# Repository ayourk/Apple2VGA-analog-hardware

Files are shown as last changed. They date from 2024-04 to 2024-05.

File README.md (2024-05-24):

V2Logo 

# Clone of ∀2 Retro Computing Analog VGA Card & PicoPal
PicoPal Logo

Design files for the ∀2 Analog series of VGA cards

## Description
Modified version of V2RetroComputing's Apple II Analog VGA Expansion Board using KiCAD 6.0.x. <br />
Changes from original:
* Moved solder jumpers to the back of the board for both the (lack of) PAL/GAL and non WiFi Pico.
* Reorganized Schematic to more easily generate a BOM with Part numbers from LSCS, DigiKey, and Mouser.
* Adopted Hans Hübner's VGA port connector break-away feature. Also reworked board to be 2 layers vs 4 layers but kept 4x bus transcievers vs Han's 2 since the chip in the 4x variant is easier to obtain.
* Added a PLCC socket for the PAL/GAL chip that is getting difficult to find.  Be sure to bridge the solder jumper on the back if you don't plan to populate this socket.
* Re-adjusted layout to provide more Analog VGA signal clarity by making the traces as short as possible between the VGA port connector and the PICO.
* Switched from IDC header style to a shielded FPC cable for less chance of signal interference when using the optional break-away feature.
* Rounded off PCB corners where it made sense.  I hate getting stabbed by PCBs (Grrrr)!

This board should still be binary compatible with the software this hardware was forked from.

### PCB Layout
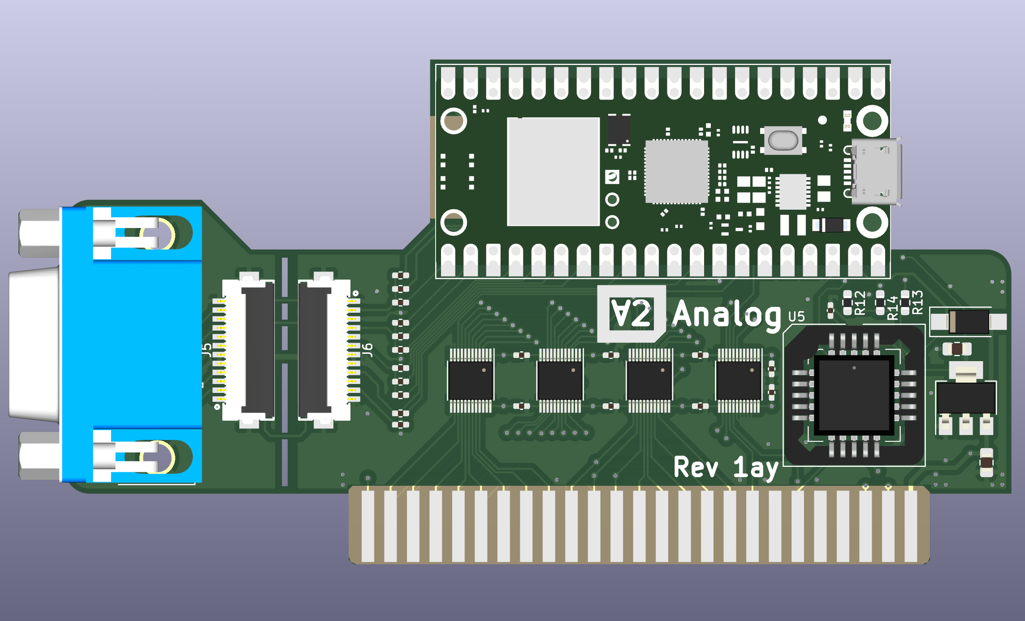
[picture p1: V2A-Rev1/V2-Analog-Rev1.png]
A2VGA Board Image V2RetroComputing's Apple II Analog VGA card


### See Also
https://github.com/V2RetroComputing/analog <br />
https://github.com/ayourk/Apple2Analog-VGA <br />
https://github.com/hanshuebner/AppleII-VGA <br />
https://github.com/markadev/AppleII-VGA <br />
[Apple II Expansion Card Size Specifications](V2A-Rev1/docs/Apple_II_ExpansionCard_Spec.txt) <br />
[Apple II Expansion Slot Pinout](V2A-Rev1/docs/Apple2SlotPinout.html) <br />
[Apple II Hardware Reference](V2A-Rev1/docs/Apple2HardwareReference.pdf) <br />
https://github.com/ayourk/Apple2Proto <br />

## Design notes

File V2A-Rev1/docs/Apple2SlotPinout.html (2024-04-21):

# Apple II Peripheral Card connector pinout

The arrow in the middle of the drawing points to the front of the Apple II | 1 | I/O SELECT | This line, normal high, will become low when the microprocessor references page $Cn, where n is the individual slot number. This signal becomes active during 00 and will drive 10 LSTTL loads*. This signal is not present on peripheral connector 0 (II+)
| 2-17 | A0-A15 | The buffered address bus. The address on these lines becomes valid during 01 and remains valid through 00. These lines will each drive 5 LSTTL loads.
| 18 | R/W | Buffered Read/Write signal. This becomes valid at the same time the address bus does, and goes high during a read cycle and low during a write. This line can drive up to 2 LSTTL loads *.
| 19 | SYNC | On peripheral connector 7 ONLY, this pin is connected to the video timing generator's SYNC signal.
| 20 | I/O STROBE | This line goes low during 00 when the address bus contains an address between $C800 and $CFFF. This line will drive 4 LSTTL loads*.
| 21 | READY | The 6502's RDY input. Pulling this line low during 01 will halt the microprocessor, with the address bus holding the address of the current location being fetched
| 22 | DMA | Pulling this line low disables the 6502's address bus and halts the microprocessor. This line is held high with a 3k resistor to +5v
| 23 | INT OUT | Daisy-chained interrupt output to lower priority devices. This pin is usually connected to pin 28 (INT IN)
| 24 | DMA OUT | Daisy-chained DMA output to lower priority devices. This pin is usually connected to pin 22 (DMA IN)
| 25 | +5V | +5 volt power supply. 500mA current is available for ALL peripheral cards.
| 26 | GND | System electrical ground
| 27 | DMA IN | Daisy-chained DMA input from higher priority devices. Usually connected to pin 24 (DMA OUT)
| 28 | INT IN | Daisy-chained interrupt input from higher priority devices. Usually connected to pin 23 (INT OUT)
| 29 | NMI | Non-Maskable Interrupt. When this line is pulled low the Apple II computer begins an interrupt cycle and jumps to the interrupt handling routine at location $3FB.
| 30 | IRQ | Interrupt ReQuest. When this line is pulled low the Apple II computer begins an interrupt cycle only if the 6502's I (Interrupt disable) flag is not set. If so, the 6502 will jump to the interrupt handling routine whose address is stored in locations $3FE and $3FF
| 31 | RESET | When this line is pulled low the microprocessor begins a RESET cycle (see page 36 of the Apple II Hardware Reference)
| 32 | INH | When this line is pulled low, all ROMs on the Apple board are disabled. This line is held high by a 2k resistor to +5v
| 33 | -12V | -12 volt power supply. Maximum current is 200mA for all peripheral boards.
| 34 | -5V | -5 volt power supply. Maximum current is 200mA for all peripheral boards
| 35 | COLOR REF | On peripheral connector 7 ONLY, this pin is connected to the 3.5Mhz COLOR REFerence signal of the video generator
| 36 | 7M | 7Mhz clock. This line will drive 2 LSTTL loads*.
| 37 | Q3 | 2Mhz asymmetrical clock. This line will drive 2 LSTTL loads*.
| 38 | Phi 01 | Microprocessor's phase one clock. This line will drive 2 LSTTL loads *.
| 39 | USER 1 | This line, when pulled low, disables ALL internal I/O address decoding**.
| 40 | Phi 00 | Microprocessors phase zero clock. This line will drive 2 LSTTL loads*.
| 41 | DEVICE SELECT | This line becomes active (low) on each peripheral connector when the address bus is holding an address between $con) and $C0nF, where n is the slot number plus $8. This line will drive 10 LSTTL loads*.
| 42-49 | D0-D7 | Buffered bi-directional data bus. The data on this line becomes valid 300nS into 00 on a write cycle, and should be stable no less than 100nS before the end of 00 on a read cycle. Each data line can drive one LSTTL load.
| 50 | +12V | +12 volt power supply. This can supply up to 250mA total for all peripheral cards.

Original information available from here (https://osites.tripod.com/peripheral.html).

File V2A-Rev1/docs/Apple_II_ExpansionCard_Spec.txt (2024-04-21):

From https://web.pdx.edu/~heiss/technotes/iigs/tn.iigs.028.html
via Archive.org: https://web.archive.org/web/20070624190021/https://web.pdx.edu/~heiss/technotes/iigs/tn.iigs.028.html

Apple IIgs #28
Interface Card Design Guidelines
Revised by Matt Deatherage (November 1988)
Written by Cameron Birse (October 1987)
This Technical Note describes suggested dimensions for interface cards for the Apple IIGS and Apple IIe upgraded sytems.

|----------------------7.00"----------------------|
__________________________________________________ __  __
|                                                 | |   |
|    The 7" dimension is specified for slots      | |   |
|    1-3 because of the optional fan which        | |   |
|    mounts on the power supply.                  | |   |
|                                                 |2.75"|
|                                                 | |   |
|                                                 | |  3.05"
|                  SLOTS 1 - 3                    | |   |
|                                                 | |   |
|_____________________________                  __|__   |
                             |__________________|_|______
                             |-------2.950"-----|-|-.375"

     |-------------------------10.00"-----------------------------------|
     |-----2.25"----|-----------------------7.75"-----------------------|
     |              ____________________________________________________ __  __
     |          _ ~                                                     | |   |
     |     _ ~                                                          | |   |
 ____ _ ~                                                               | |   |
 |   |                                                                  | |   |
 |   |                                                                  |2.75"|
 |   |                                                                  | |   |
2.20"|                                                                  | 3.05"
 |   |                       SLOTS 4 - 7                                | |   |
 |   |                                                                  | |   |
 __  |______________________________________________                  __|__   |
                                                   |__________________|_|______
                                                   |-------2.950"-----|-|-.375"

     |-------------------------10.00"-----------------------------------|
     |-----2.25"----|-----------------------7.75"-----------------------|
     |              ____________________________________________________ __
     |          _ ~                                                     | |
     |     _ ~                                                          | |
 ____ _ ~                                                               | |
 |   |                                                                  | |
 |   |                                                                  |2.75"
 |   |                                                                  | |
2.20"|                                                                  | |
 |   |                       SLOTS 4 - 7                                | |
 |   |                                                                  | |
 ____|_______                _________________   _______________________|_____
.35" |-.750-|                |                |  |                  .630" -|
 ____|______|________________|                |__|_________________________|__
     |--------3.02"----------|                |  |                         |
     |---------------------6.385"-------------|--|----------3.215"---------|
                                              .40"

Technical Notes
This and all of the other Apple II Technical Notes have been converted to HTML by Aaron Heiss as a public service to the Apple II community, with permission by Apple Computer, Inc. Any and all trademarks, registered and otherwise, are properties of their owners.

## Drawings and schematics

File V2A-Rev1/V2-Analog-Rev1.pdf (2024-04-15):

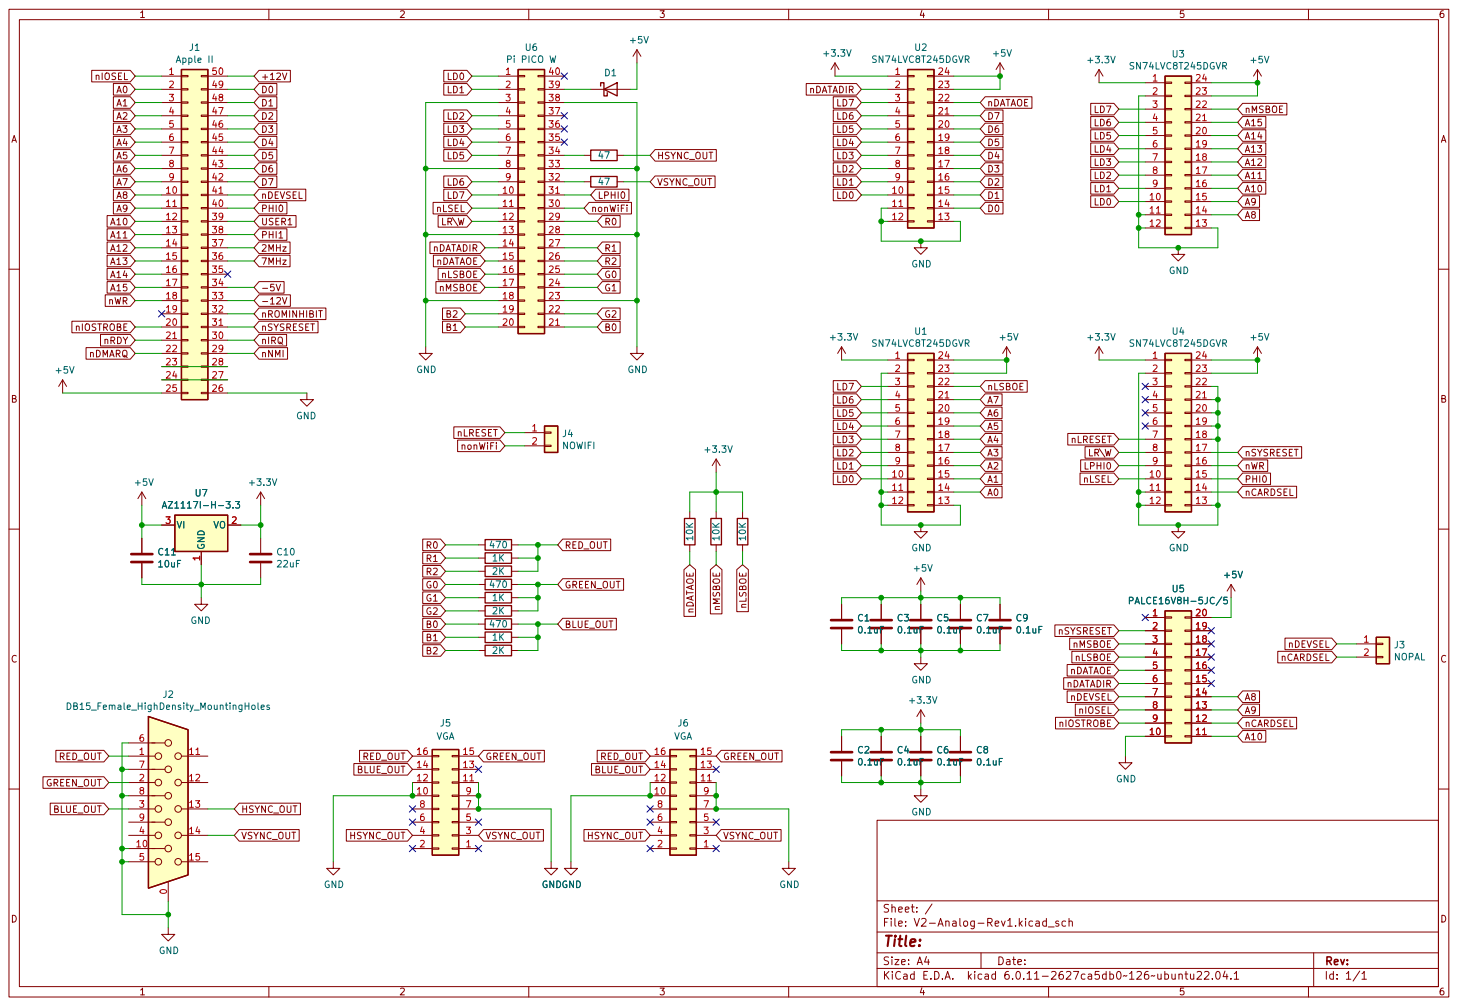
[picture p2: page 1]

Id: 1/1 Title: File: V2-Analog-Rev1.kicad_sch Sheet: / C10

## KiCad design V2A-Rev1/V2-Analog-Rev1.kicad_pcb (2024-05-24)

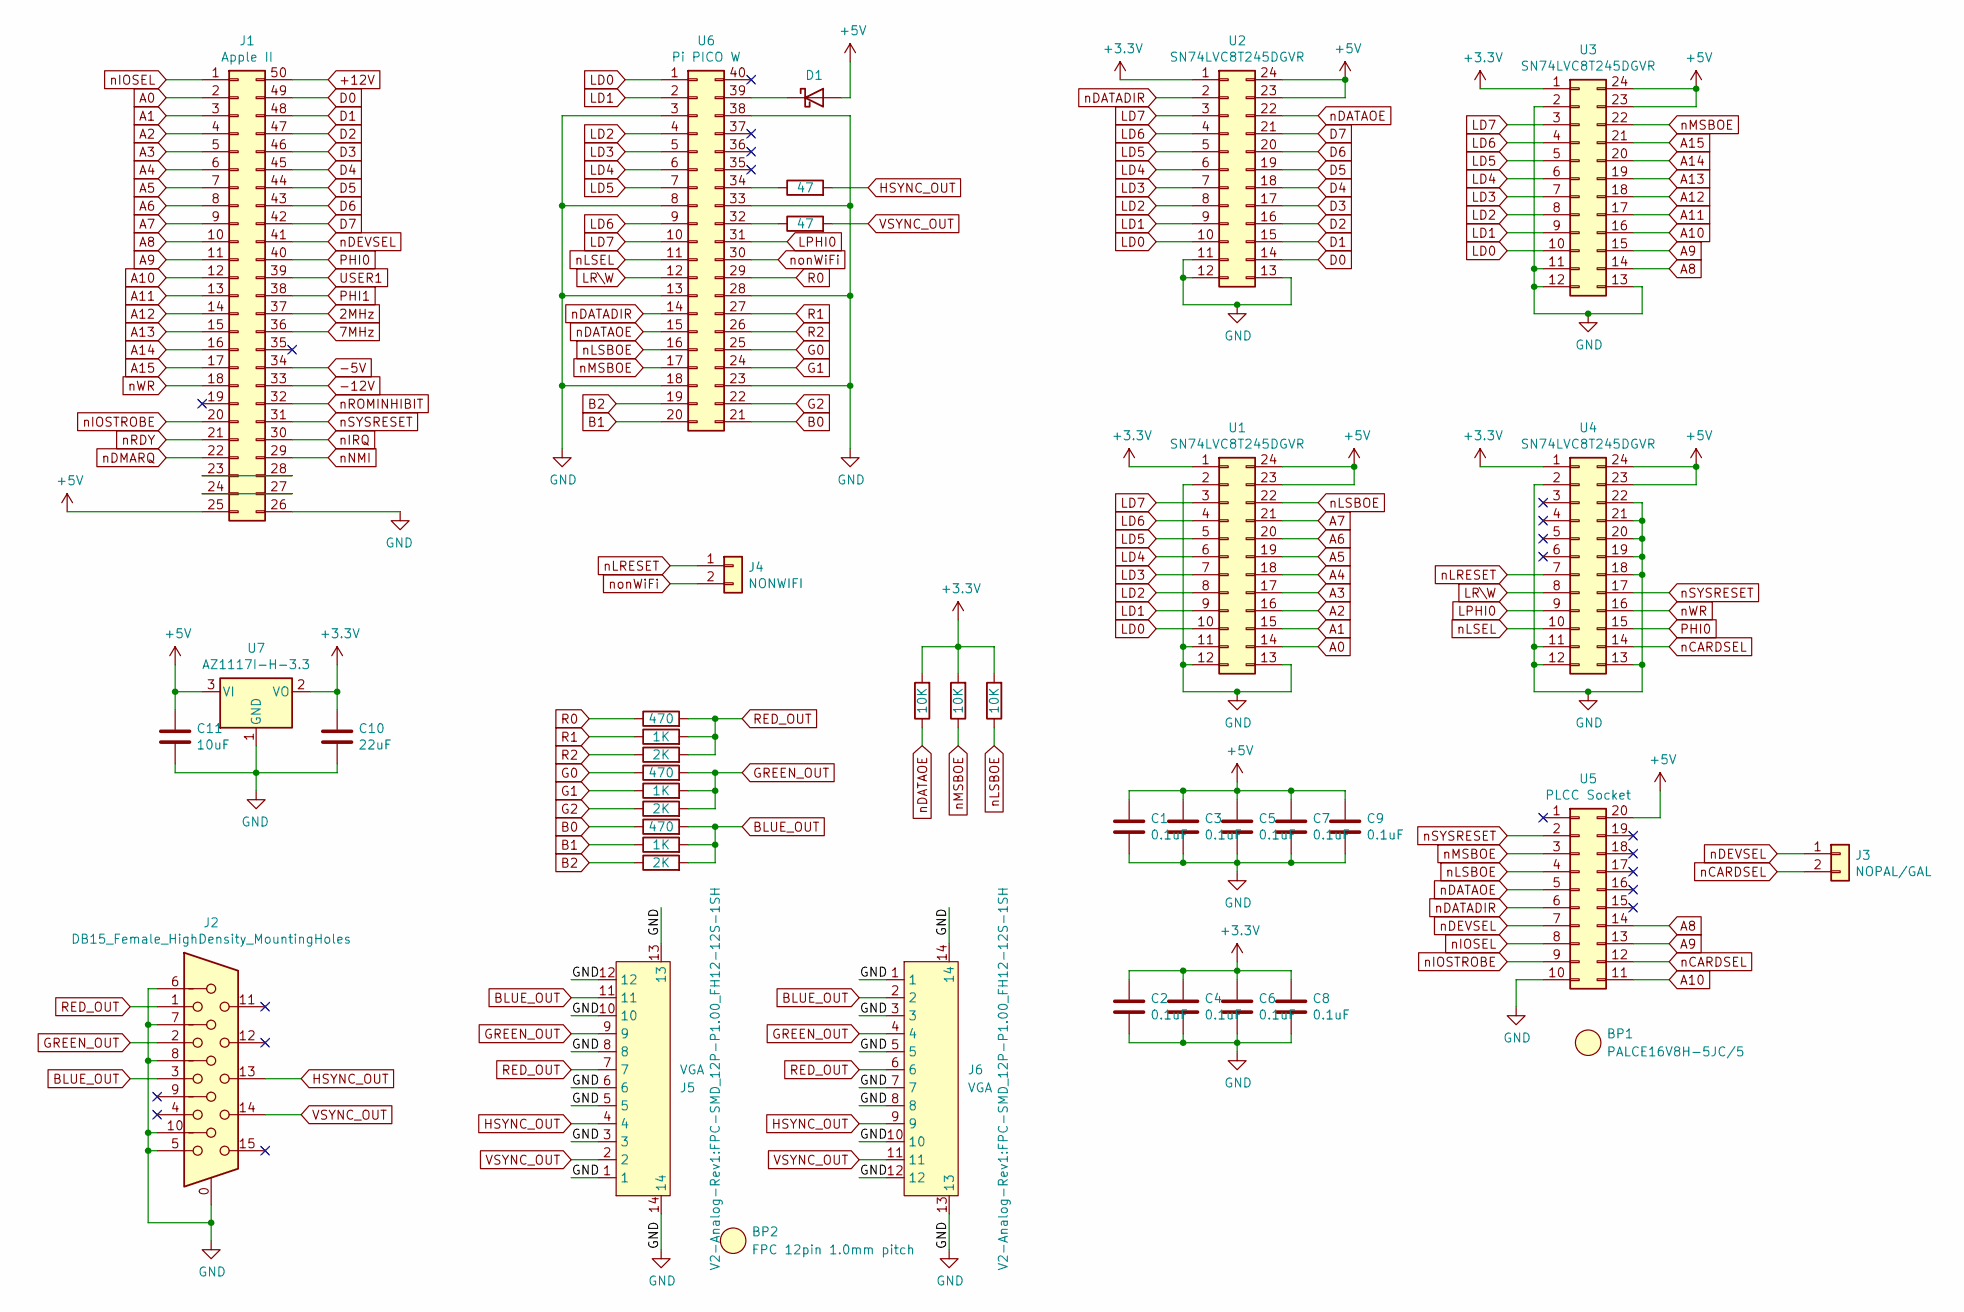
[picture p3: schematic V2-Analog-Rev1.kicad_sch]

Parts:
BP1: PALCE16V8H-5JC/5; BOM_Placeholder; MPN PALCE16V8H-5JC/5; LCSC C3292615
BP2: FPC 12pin 1.0mm pitch; BOM_Placeholder; MPN 0152670279; LCSC C18108667
C1, C2, C3, C4, C5, C6, C7, C8, C9: 0.1uF; C_0402_1005Metric_Pad0.74x0.62mm_HandSolder; MPN CL05B104KA5NNNC; LCSC C155422
C10: 22uF; C_0805_2012Metric_Pad1.18x1.45mm_HandSolder; MPN CL21A226MAYNNNE; LCSC C602037
C11: 10uF; C_0805_2012Metric_Pad1.18x1.45mm_HandSolder; MPN CL21A106KAYNNNE; LCSC C15850
D1: D_Schottky; D_SMA_Handsoldering; MPN SS14F; LCSC C64880
J1: Apple II; AppleII
J2: DB15_Female_HighDensity_MountingHoles; DSUB-15-HD_Female_Horizontal_P2.29x1.98mm_EdgePinOffset3.03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; MPN L77HDE15SD1CH4FVGA; LCSC C138387
J3: NOPAL/GAL; SolderJumper-2_P1.3mm_Open_TrianglePad1.0x1.5mm
J4: NONWIFI; SolderJumper-2_P1.3mm_Open_TrianglePad1.0x1.5mm
J5, J6: VGA; FPC-SMD_12P-P1.00_FH12-12S-1SH; MPN FH12-12S-1SH(55); LCSC C5148307
R1, R4, R7: 470; R_0402_1005Metric_Pad0.72x0.64mm_HandSolder; MPN ERJ-2RKF4700X; LCSC C413076
R2, R5, R8: 1K; R_0402_1005Metric_Pad0.72x0.64mm_HandSolder; MPN ERJ-2RKF1001X; LCSC C242161
R3, R6, R9: 2K; R_0402_1005Metric_Pad0.72x0.64mm_HandSolder; MPN ERJ-2RKF2001X; LCSC C413086
R10, R11: 47; R_0402_1005Metric_Pad0.72x0.64mm_HandSolder; MPN ERJ-2RKF47R0X; LCSC C413056
R12, R13, R14: 10K; R_0603_1608Metric_Pad0.98x0.95mm_HandSolder; MPN ERJ-3EKF1002V; LCSC C191124
U1, U2, U3, U4: SN74LVC8T245DGVR; TSSOP-24_4.4x5mm_P0.4mm; MPN SN74LVC8T245DGVR; LCSC C364886
U5: PLCC Socket; A-CCS_020-Z-SM_SMD-Socket; MPN A-CCS 020-Z-SM; LCSC C7058802
U6: Pi PICO W; DIP-40_W16.51mm_SMDSocket_LongPads; MPN SC0918; LCSC C7203003
U7: AZ1117I-H-3.3; SOT-223-3_TabPin2; MPN AZ1117H-3.3TRG1; LCSC C110474

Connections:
2MHz: J1.37
7MHz: J1.36
+3V3: C2.1, C4.1, C6.1, C8.1, C10.1, R12.2, R13.2, R14.2, U1.1, U2.1, U3.1, U4.1, U7.2 (VO)
+5V: C1.1, C3.1, C5.1, C7.1, C9.1, C11.1, D1.2 (A), J1.25, U1.23, U1.24, U2.23, U2.24, U3.23, U3.24, U4.23, U4.24, U5.20, U7.3 (VI)
+12V: J1.50
-5V: J1.34
-12V: J1.33
A0: J1.2, U1.14
A1: J1.3, U1.15
A2: J1.4, U1.16
A3: J1.5, U1.17
A4: J1.6, U1.18
A5: J1.7, U1.19
A6: J1.8, U1.20
A7: J1.9, U1.21
A8: J1.10, U3.14, U5.14
A9: J1.11, U3.15, U5.13
A10: J1.12, U3.16, U5.11
A11: J1.13, U3.17
A12: J1.14, U3.18
A13: J1.15, U3.19
A14: J1.16, U3.20
A15: J1.17, U3.21
B0: R7.1, U6.21
B1: R8.1, U6.20
B2: R9.1, U6.19
BLUE_OUT: J2.3, J5.11, J6.2, R7.2, R8.2, R9.2
D0: J1.49, U2.14
D1: J1.48, U2.15
D2: J1.47, U2.16
D3: J1.46, U2.17
D4: J1.45, U2.18
D5: J1.44, U2.19
D6: J1.43, U2.20
D7: J1.42, U2.21
G0: R4.1, U6.25
G1: R5.1, U6.24
G2: R6.1, U6.22
GND: C1.2, C2.2, C3.2, C4.2, C5.2, C6.2, C7.2, C8.2, C9.2, C10.2, C11.2, J1.26, J2.0, J2.5, J2.6, J2.7, J2.8, J2.10, J5.1, J5.3, J5.5, J5.6, J5.8, J5.10, J5.12, J5.13, J5.14, J6.1, J6.3, J6.5, J6.7, J6.8, J6.10, J6.12, J6.13, J6.14, U1.2, U1.11, U1.12, U1.13, U2.11, U2.12, U2.13, U3.2, U3.11, U3.12, U3.13, U4.2, U4.11, U4.12, U4.13, U4.18, U4.19, U4.20, U4.21, U4.22, U5.10, U6.3, U6.8, U6.13, U6.18, U6.23, U6.28, U6.33, U6.38, U7.1 (GND)
GREEN_OUT: J2.2, J5.9, J6.4, R4.2, R5.2, R6.2
HSYNC_OUT: J2.13, J5.4, J6.9, R10.2
LD0: U1.10, U2.10, U3.10, U6.1
LD1: U1.9, U2.9, U3.9, U6.2
LD2: U1.8, U2.8, U3.8, U6.4
LD3: U1.7, U2.7, U3.7, U6.5
LD4: U1.6, U2.6, U3.6, U6.6
LD5: U1.5, U2.5, U3.5, U6.7
LD6: U1.4, U2.4, U3.4, U6.9
LD7: U1.3, U2.3, U3.3, U6.10
LPHI0: U4.9, U6.31
LR\W: U4.8, U6.12
unnamed: D1.1 (K), U6.39
unnamed: J1.23, J1.28
unnamed: J1.24, J1.27
unnamed: R10.1, U6.34
unnamed: R11.1, U6.32
PHI0: J1.40, U4.15
PHI1: J1.38
R0: R1.1, U6.29
R1: R2.1, U6.27
R2: R3.1, U6.26
RED_OUT: J2.1, J5.7, J6.6, R1.2, R2.2, R3.2
USER1: J1.39
VSYNC_OUT: J2.14, J5.2, J6.11, R11.2
nCARDSEL: J3.2, U4.14, U5.12
nDATADIR: U2.2, U5.6, U6.14
nDATAOE: R12.1, U2.22, U5.5, U6.15
nDEVSEL: J1.41, J3.1, U5.7
nDMARQ: J1.22
nIOSEL: J1.1, U5.8
nIOSTROBE: J1.20, U5.9
nIRQ: J1.30
nLRESET: J4.1, U4.7
nLSBOE: R14.1, U1.22, U5.4, U6.16
nLSEL: U4.10, U6.11
nMSBOE: R13.1, U3.22, U5.3, U6.17
nNMI: J1.29
nRDY: J1.21
nROMINHIBIT: J1.32
nSYSRESET: J1.31, U4.17, U5.2
nWR: J1.18, U4.16
nonWiFi: J4.2, U6.30

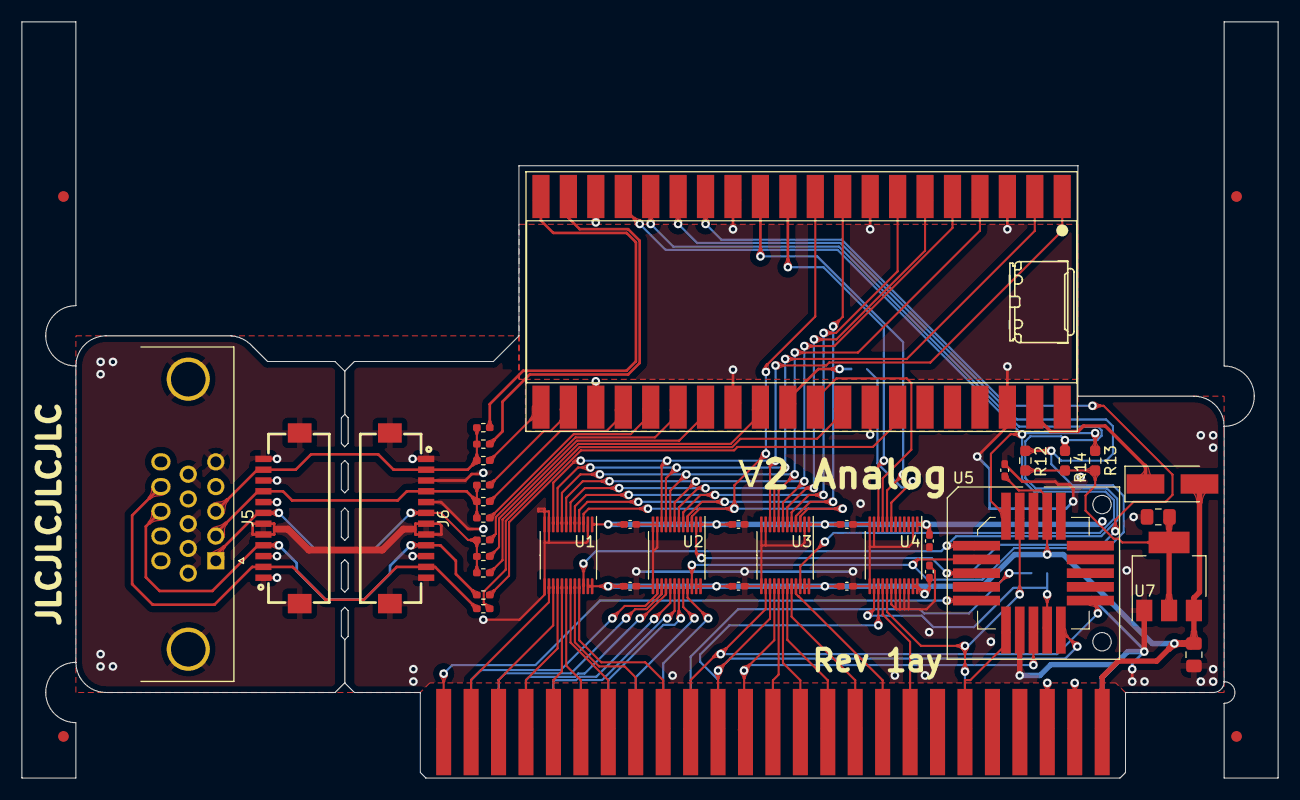
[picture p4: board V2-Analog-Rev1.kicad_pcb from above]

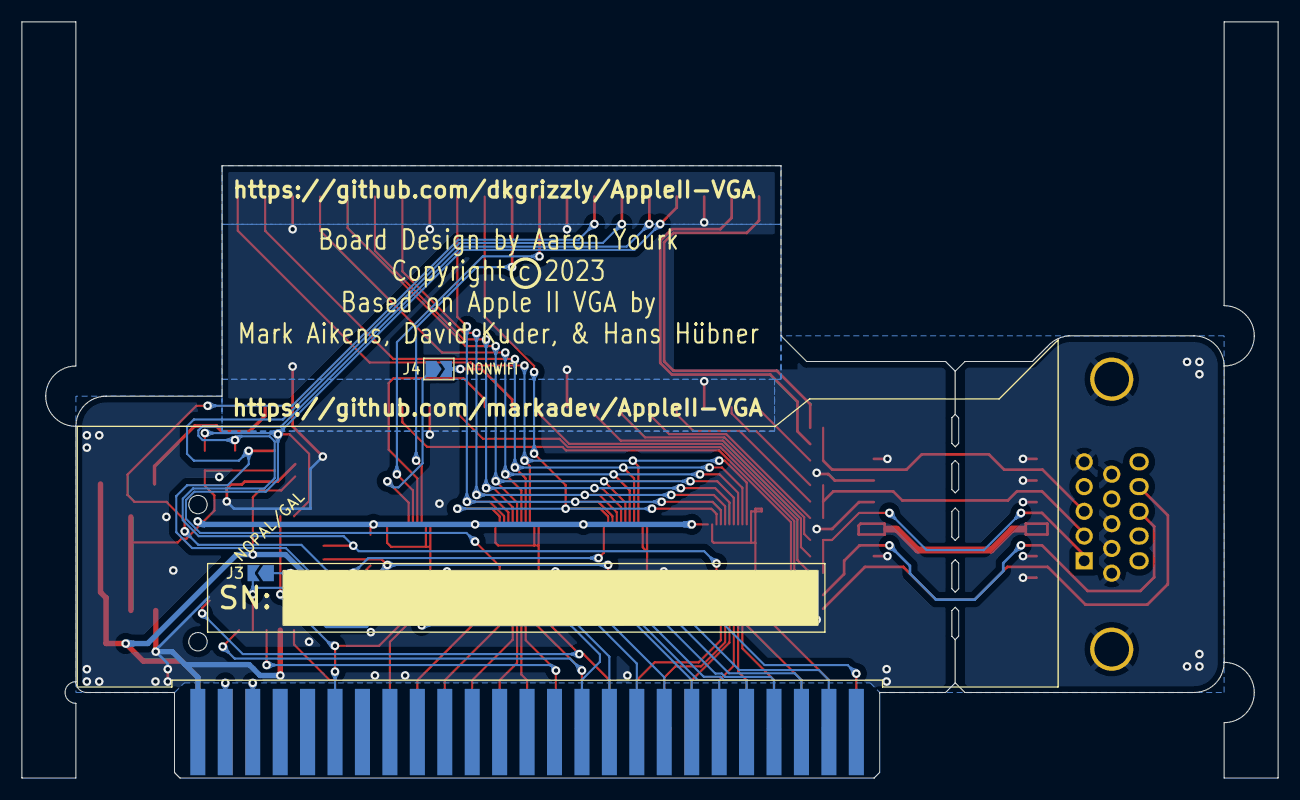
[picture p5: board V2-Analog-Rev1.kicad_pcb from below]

Board: 2 copper layers, 116.3 x 70.0 mm, 41 parts (2 on the bottom side), 70 nets.

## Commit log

2024-04-15 My reinterpretation of V2RetroComputing's Analog VGA Board.
    [V2-Analog-Rev1.kicad_pcb, V2-Analog-Rev1.kicad_sch]
2024-04-15 Update design to use a PLCC socket for PAL/GAL.
    [V2-Analog-Rev1.kicad_pcb, V2-Analog-Rev1.kicad_sch]
2024-04-21 Added socket for PLCC. Reorganized layout for improved VGA picture clarity.
    [V2-Analog-Rev1.kicad_pcb, V2-Analog-Rev1.kicad_sch]
2024-05-15 Added Left and Right Fiducial break away Rails
    [V2-Analog-Rev1.kicad_pcb, V2-Analog-Rev1.kicad_sch]
2024-05-21 Fix issues with JLCPCB manufacturing standards.
    [V2-Analog-Rev1.kicad_pcb]
2024-05-24 Added V-scoring suggestion to VGA break-away port. Added to Silkscreen MicroUSB port location from PICO.
    [V2-Analog-Rev1.kicad_pcb]
